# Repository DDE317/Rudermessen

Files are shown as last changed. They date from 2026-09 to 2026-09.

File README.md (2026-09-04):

# Rudermesser (Arduino Nano 33 BLE)

Misst den Ruderausschlag eines Modellflugzeugs in Millimetern und zeigt ihn live auf dem Smartphone an - per Bluetooth.

 

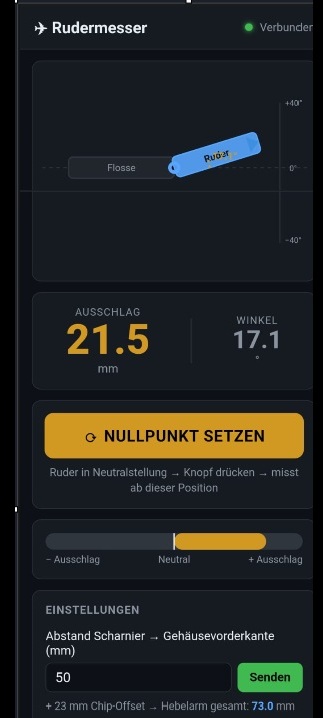
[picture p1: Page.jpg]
Rudermesser App


---

## Was macht das Projekt?

Ein Arduino Nano 33 BLE wird an das Ruder eines Modellflugzeugs geklemmt. Der eingebaute IMU-Sensor (LSM9DS1) misst den Winkel der Ruderbewegung und rechnet ihn in Millimeter Ausschlag um. Die Anzeige erfolgt live auf dem Smartphone über eine Web-App per Bluetooth (BLE).

---

## Berechnung

```
mm Ausschlag = sin(Winkel) × (Hebelarm + 23 mm)
```

- **23 mm** = fester Offset (Vorderkante Gehäuse bis IMU-Chip-Mitte)
- **Hebelarm** = Abstand Scharnierachse bis Gehäusevorderkante (in der App einstellbar)

---

## Benötigte Hardware

| Teil | Beschreibung |
|---|---|
| Arduino Nano 33 BLE | Mikrocontroller mit BLE + IMU (LSM9DS1) |
| 1S LiPo | Akku zur Stromversorgung (z.B. 500 mAh) |

### Stromversorgung

- LiPo **+** → Arduino **3.3V Pin**
- LiPo **−** → Arduino **GND Pin**

> Ein voller 1S LiPo (4.2V) liegt knapp über 3.3V - der interne Regler verträgt das. Achtung: kein Tiefentladeschutz, Akku rechtzeitig laden.

---

## Teil A: Firmware auf den Arduino laden

Du brauchst **PlatformIO** (kostenlos) - als VS Code Extension oder als PlatformIO Core.

### 1. Projekt herunterladen
- Oben auf den grünen **"Code"** Knopf → **"Download ZIP"**
- ZIP entpacken

### 2. Projekt öffnen
- Ordner in VS Code / Kiro öffnen (mit PlatformIO Extension)

### 3. Arduino anschließen
- Arduino Nano 33 BLE per USB an den PC anschließen

### 4. Hochladen
- In PlatformIO auf **Upload** klicken (Pfeil-Symbol)
- Oder im Terminal:
  ```
  pio run -t upload
  ```
- Beim ersten Mal werden automatisch alle Bibliotheken heruntergeladen

> **Tipp:** Falls der Upload fehlschlägt ("No device found"), den **Reset-Knopf am Arduino zweimal schnell drücken** (Doppelklick) und dann erneut hochladen. Der Nano 33 BLE wechselt beim Upload kurz den COM-Port.

---

## Teil B: Web-App einrichten

Die Web-App läuft als **PWA (Progressive Web App)** und funktioniert nach der Installation offline. Web Bluetooth funktioniert nur in **Chrome auf Android** (nicht auf iOS).

### Variante 1: Über GitHub Pages (empfohlen)

Wenn du die App über GitHub Pages hostest, brauchst du keinen eigenen Webserver:

1. Im Repository unter **Settings → Pages** die Quelle auf `main` / `root` stellen
2. Nach ein paar Minuten ist die App erreichbar unter:
   `https://DEINNAME.github.io/REPONAME/webapp/`
3. Diese Adresse auf dem Handy in **Chrome** öffnen
4. **3-Punkte-Menü → "App installieren"** → die App liegt dann auf dem Homescreen und läuft offline

### Variante 2: Lokal über den PC (zum Testen)

1. Im `webapp` Ordner einen lokalen Webserver starten (Python):
   ```
   python -m http.server 8080 --directory webapp
   ```
2. PC-IP-Adresse herausfinden (`ipconfig`)
3. Am Handy im gleichen WLAN: `http://<PC-IP>:8080` öffnen

---

## Bedienung

1. Arduino ans Ruder montieren und mit Strom versorgen
2. Web-App öffnen (Chrome auf Android)
3. **"Verbinden"** drücken → **"Rudermesser"** auswählen
4. Ruder in Neutralstellung → **"Nullpunkt setzen"**
5. Bei Einstellungen den Abstand Scharnier → Gehäusevorderkante eingeben → **"Senden"**
6. Ruder bewegen → Ausschlag in mm ablesen

---

## Projektstruktur

```
Rudder Messen/
├── platformio.ini     PlatformIO Konfiguration (Board, Bibliotheken)
├── src/
│   └── main.cpp       Arduino Firmware (IMU auslesen, BLE senden)
├── webapp/            Web-App (PWA)
│   ├── index.html
│   ├── style.css
│   ├── app.js
│   ├── manifest.json
│   ├── service-worker.js
│   └── icon-192.png / icon-512.png
└── cad/               3D-Gehäuse (STL / STEP zum Drucken)
```

---

## Verwendete Bibliotheken

- Arduino_LSM9DS1 (IMU-Sensor)
- ArduinoBLE (Bluetooth)

Beide werden von PlatformIO automatisch installiert.

---

## Einbaulage / Achsen anpassen

Der Arduino ist um 180° gedreht eingebaut (USB hinten). Das wird in der Firmware korrigiert. Falls die Messung die falsche Achse oder Richtung zeigt, kann in `src/main.cpp` in der Funktion `getAngle()` die Achse angepasst werden.

---

## Fehlerbehebung

| Problem | Lösung |
|---|---|
| Upload "No device found" | Reset-Knopf 2x schnell drücken, erneut hochladen |
| App findet kein Gerät | Nur Chrome auf Android, Bluetooth am Handy an |
| Werte falsch herum | Achse/Vorzeichen in `getAngle()` anpassen |
| Nullpunkt nicht exakt 0 | Nach dem Kalibrieren kurz warten (Filter) |

---

## Schwesterprojekt

Für eine plattformunabhängige Lösung (Android **und** iPhone, ohne Bluetooth, ohne App-Installation) siehe **Rudder Messen ESP32** - dort läuft alles über einen WLAN-Hotspot des ESP32.

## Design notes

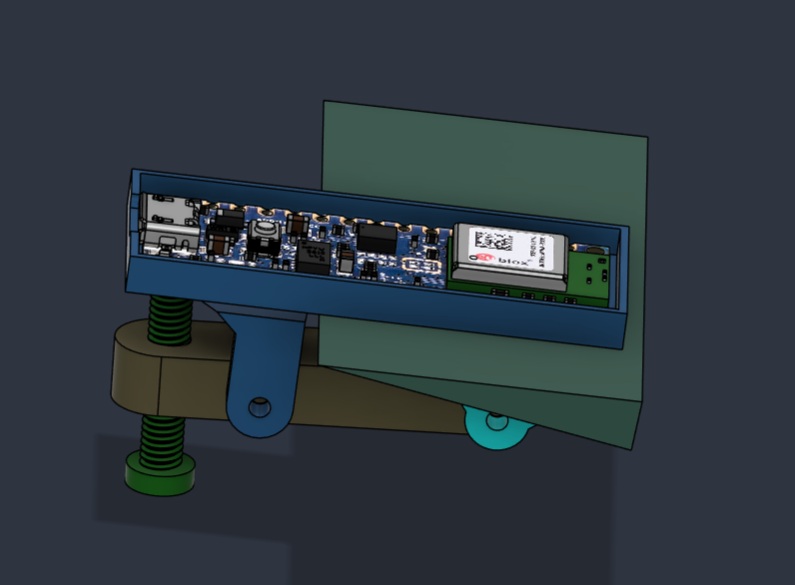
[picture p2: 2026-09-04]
cad/1 Halter BLE 33.jpg

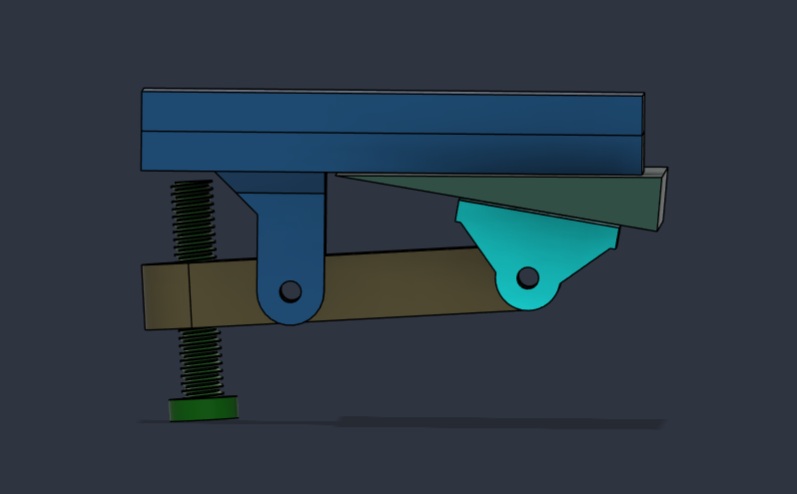
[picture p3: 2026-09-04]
cad/Halter BLE 33.jpg

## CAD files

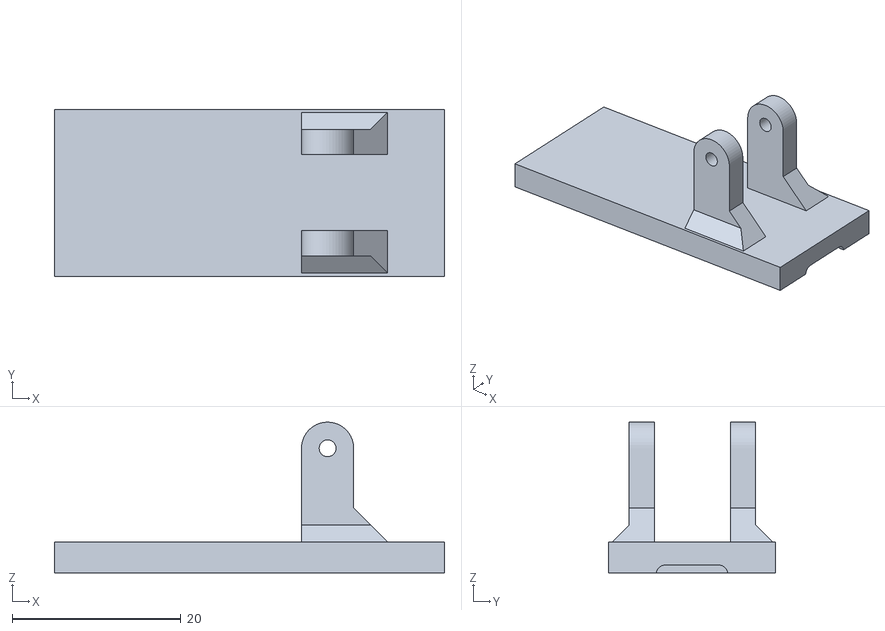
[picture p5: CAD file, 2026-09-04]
cad/Unter Teil .stl
46.2 x 19.8 x 17.8

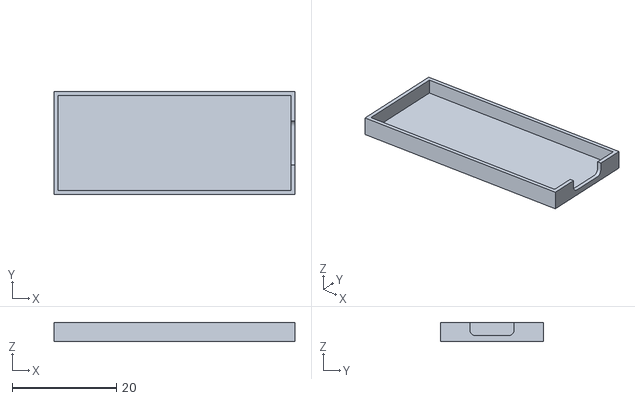
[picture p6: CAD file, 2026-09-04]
cad/Oberteil .stl
46.2 x 19.8 x 3.65

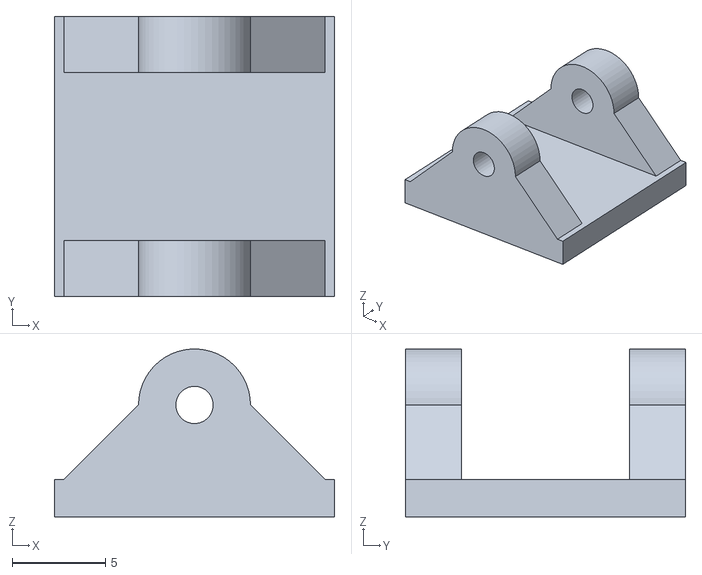
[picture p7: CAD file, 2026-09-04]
cad/Druckplatte.stl
15.0 x 15.0 x 8.99

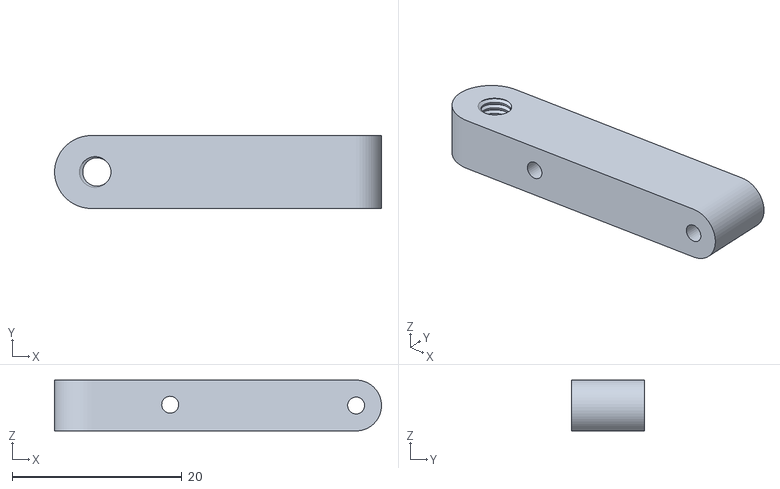
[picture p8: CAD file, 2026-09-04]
cad/Strebe.stl
38.6 x 8.60 x 6.00

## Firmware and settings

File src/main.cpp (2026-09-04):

/*
 * Rudermesser - Arduino Nano 33 BLE
 * 
 * Misst den Ruderausschlag über den eingebauten IMU (LSM9DS1)
 * und sendet die Daten per BLE an eine Web-App.
 * 
 * Einbaulage: Arduino um 180° gedreht (USB hinten)
 * Fester Offset: 23mm (Vorderkante Gehäuse bis IMU-Chip Mitte)
 */

#include <Arduino_LSM9DS1.h>
#include <ArduinoBLE.h>

// ── Fester Hardware-Offset ──────────────────────────────────────────────────
const float CHIP_OFFSET_MM = 23.0f;

// ── BLE Service & Characteristics ───────────────────────────────────────────
BLEService rudermesserService("12345678-1234-1234-1234-123456789ABC");

// Senden: aktueller Winkel in 0.01° (int16) und Ausschlag in 0.1mm (int16)
BLEIntCharacteristic angleChar(
    "12345678-1234-1234-1234-123456789ABD",
    BLERead | BLENotify
);
BLEIntCharacteristic deflectionChar(
    "12345678-1234-1234-1234-123456789ABE",
    BLERead | BLENotify
);

// Empfangen: Hebelarm (Abstand Scharnier → Gehäusevorderkante) in mm (*10 als int)
BLEIntCharacteristic leverArmChar(
    "12345678-1234-1234-1234-123456789ABF",
    BLERead | BLEWrite
);

// Empfangen: Nullpunkt-Befehl (1 = kalibrieren)
BLEByteCharacteristic calibrateChar(
    "12345678-1234-1234-1234-123456789AC0",
    BLERead | BLEWrite
);

// ── Globale Variablen ────────────────────────────────────────────────────────
float zeroAngle   = 0.0f;   // Nullpunkt-Winkel
float leverArm_mm = 50.0f;  // Standard-Hebelarm in mm (einstellbar per App)
float filteredAngle = 0.0f; // Geglätteter Winkel

// Tiefpassfilter - je kleiner der Wert desto ruhiger (0.0-1.0)
// 0.1 = sehr ruhig/träge, 0.3 = ausgewogen, 0.5 = schnell
const float FILTER_ALPHA = 0.15f;

unsigned long lastSend = 0;
const unsigned long SEND_INTERVAL_MS = 50; // 20 Hz

// ── Hilfsfunktion: Winkel aus Beschleunigungssensor ─────────────────────────
float getAngle() {
    float ax, ay, az;
    if (!IMU.accelerationAvailable()) return 0.0f;
    IMU.readAcceleration(ax, ay, az);

    // 180° Korrektur für umgekehrten Einbau (USB hinten): X und Z invertieren
    ax = -ax;
    az = -az;

    // Winkel um die Querachse (rauf/runter Bewegung = Ruderausschlag)
    // ax = Längsachse, az = Hochachse → misst Neigung rauf/runter
    float angle = atan2(ax, az) * 180.0f / PI;
    return angle;
}

// ── Setup ────────────────────────────────────────────────────────────────────
void setup() {
    Serial.begin(115200);
    delay(1000);

    // IMU initialisieren
    if (!IMU.begin()) {
        Serial.println("IMU Fehler!");
        while (1);
    }
    Serial.println("IMU OK");

    // BLE initialisieren
    if (!BLE.begin()) {
        Serial.println("BLE Fehler!");
        while (1);
    }

    BLE.setLocalName("Rudermesser");
    BLE.setAdvertisedService(rudermesserService);

    rudermesserService.addCharacteristic(angleChar);
    rudermesserService.addCharacteristic(deflectionChar);
    rudermesserService.addCharacteristic(leverArmChar);
    rudermesserService.addCharacteristic(calibrateChar);

    BLE.addService(rudermesserService);

    // Standardwerte setzen
    angleChar.writeValue(0);
    deflectionChar.writeValue(0);
    leverArmChar.writeValue((int)(leverArm_mm * 10));
    calibrateChar.writeValue(0);

    BLE.advertise();
    Serial.println("BLE bereit - suche nach Verbindung...");
}

// ── Loop ─────────────────────────────────────────────────────────────────────
void loop() {
    BLEDevice central = BLE.central();

    if (central) {
        Serial.print("Verbunden mit: ");
        Serial.println(central.address());

        while (central.connected()) {

            // ── Einstellungen von App empfangen ──────────────────────────
            if (leverArmChar.written()) {
                leverArm_mm = leverArmChar.value() / 10.0f;
                Serial.print("Neuer Hebelarm: ");
                Serial.print(leverArm_mm);
                Serial.println(" mm");
            }

            if (calibrateChar.written() && calibrateChar.value() == 1) {
                zeroAngle = getAngle();
                filteredAngle = 0.0f; // Filter sofort auf Null setzen
                calibrateChar.writeValue(0);
                Serial.print("Nullpunkt gesetzt: ");
                Serial.print(zeroAngle);
                Serial.println("°");
            }

            // ── Messung senden ────────────────────────────────────────────
            if (millis() - lastSend >= SEND_INTERVAL_MS) {
                lastSend = millis();

                float rawAngle   = getAngle();
                float angle      = rawAngle - zeroAngle;

                // Winkel auf -180 bis +180 normalisieren
                while (angle > 180.0f)  angle -= 360.0f;
                while (angle < -180.0f) angle += 360.0f;

                // Tiefpassfilter anwenden
                filteredAngle = FILTER_ALPHA * angle + (1.0f - FILTER_ALPHA) * filteredAngle;

                float totalLever = leverArm_mm + CHIP_OFFSET_MM;
                float deflection = sin(filteredAngle * PI / 180.0f) * totalLever;

                // Winkel in 0.01° senden, Ausschlag in 0.1mm
                angleChar.writeValue((int)(filteredAngle * 100));
                deflectionChar.writeValue((int)(deflection * 10));

                // Debug-Ausgabe
                Serial.print("Winkel: ");
                Serial.print(filteredAngle, 2);
                Serial.print("°  Ausschlag: ");
                Serial.print(deflection, 1);
                Serial.println(" mm");
            }
        }

        Serial.println("Verbindung getrennt");
    }
}

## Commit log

2026-09-04 Arduino Code, README und gitignore hinzugefuegt
2026-09-04 Rudermesser ESP32 - erste Version
2026-09-04 Ausfuehrliche Nachbau-Anleitung und kompletter Code
2026-09-04 Anleitung, Code und CAD-Ordner
    [Druckplatte.stl, Oberteil .stl, Strebe.stl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]
